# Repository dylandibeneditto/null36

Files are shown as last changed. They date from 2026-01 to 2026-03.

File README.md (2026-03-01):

<picture align="center">
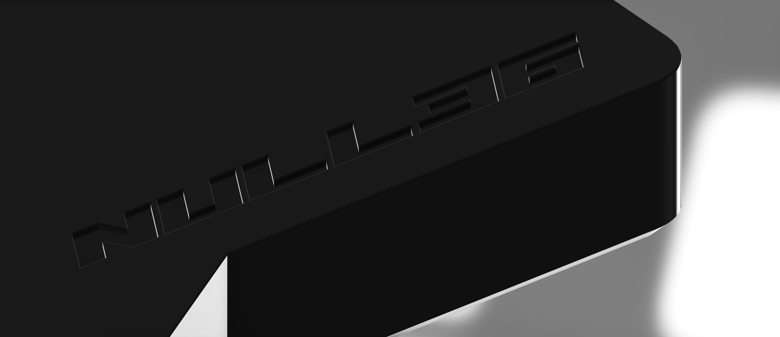
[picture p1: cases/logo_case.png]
null36
    
</picture>

<h1 align="center">null36</h1>

36-Key wireless split ortho column-staggered MX keyboard. Controlled by any Nice!Nano V2 compatible MCU, and support for SSD1306 OLED displays.

# Layout and Keymap

null36 layout

# PCB

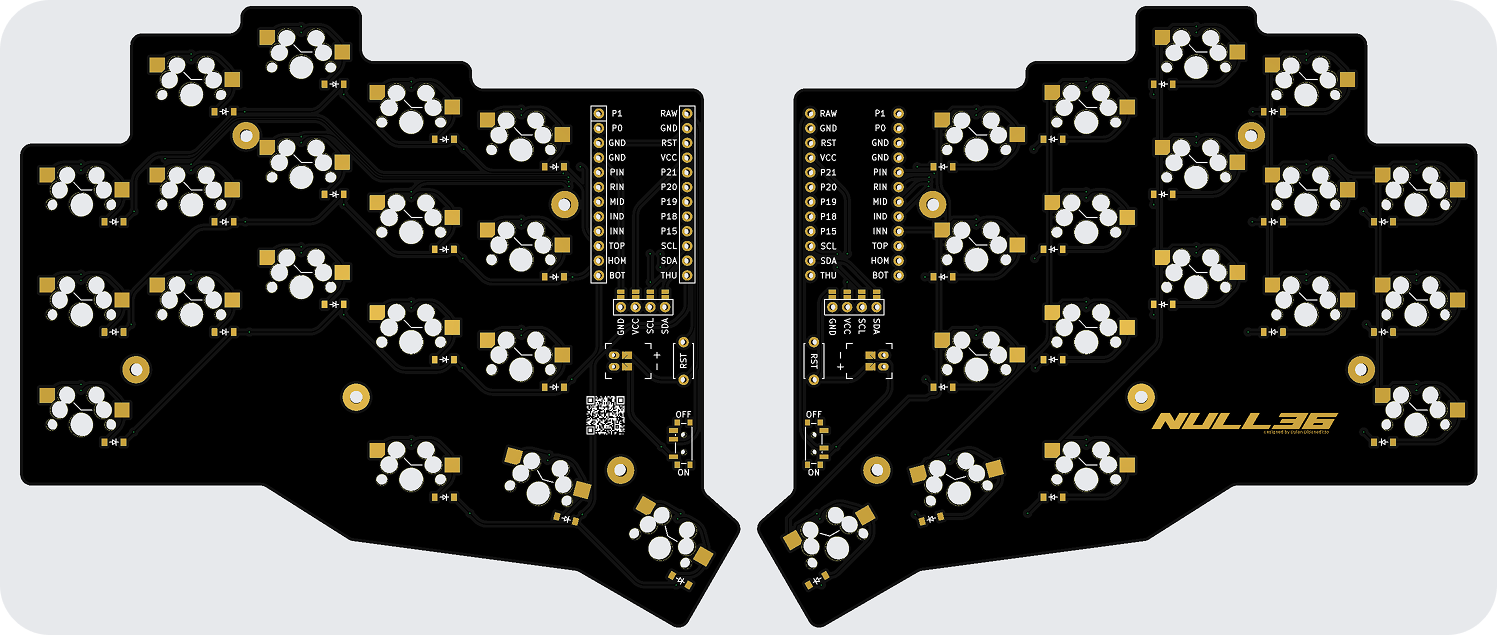
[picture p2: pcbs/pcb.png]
null36 pcb


[/pcbs](./pcbs)
> This PCB is reversible. When assembling, solder together the pads above the OLED display header, the pads next to the battery jack (the jack goes on the underside of the pcb), and diodes can go on either the front or back, as long as they follow the direction of the silkscreen

# Case

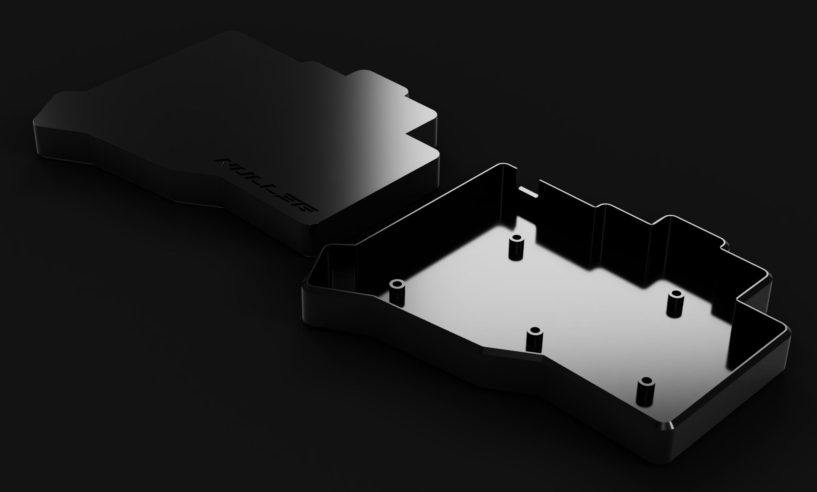
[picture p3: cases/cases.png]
null36 case


[/cases](./cases)

# Photos

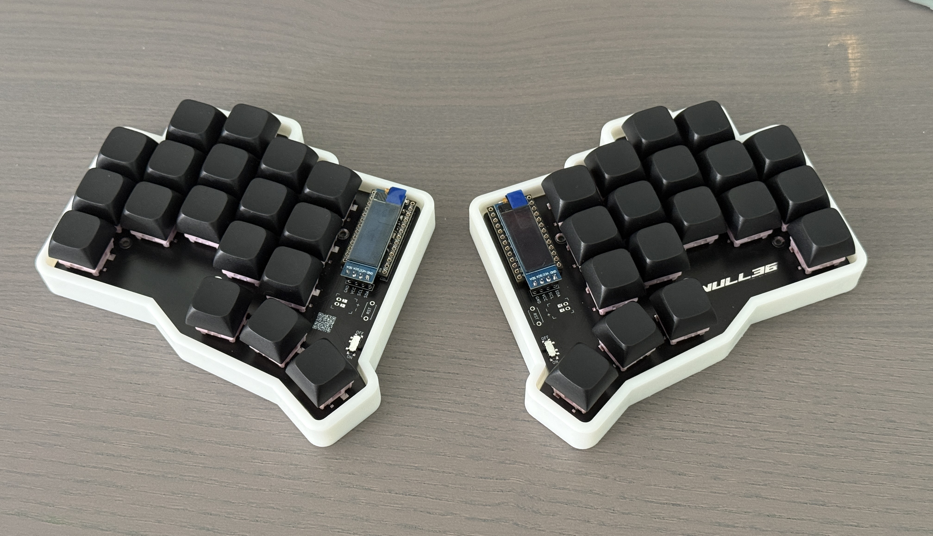
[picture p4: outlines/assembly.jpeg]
Assembly picture


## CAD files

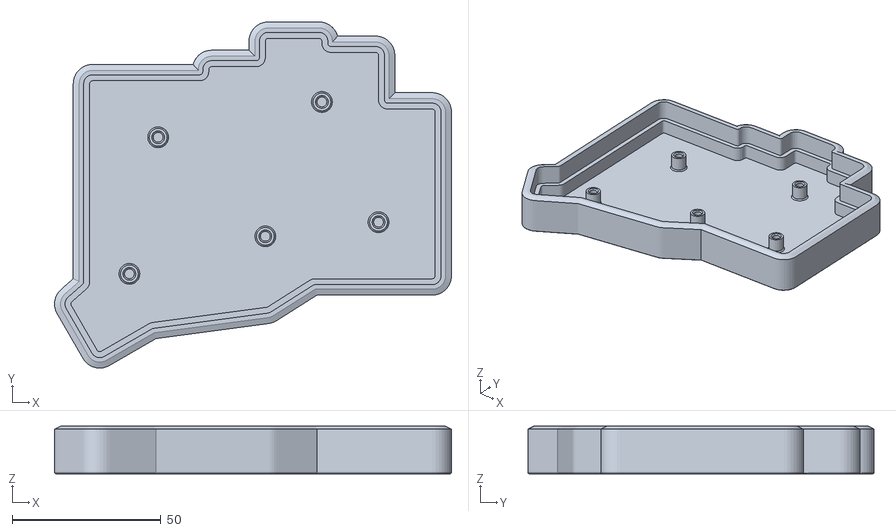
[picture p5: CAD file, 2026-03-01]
cases/right_case.stl
133.3 x 116.2 x 16.0

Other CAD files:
cases/left_case.stl

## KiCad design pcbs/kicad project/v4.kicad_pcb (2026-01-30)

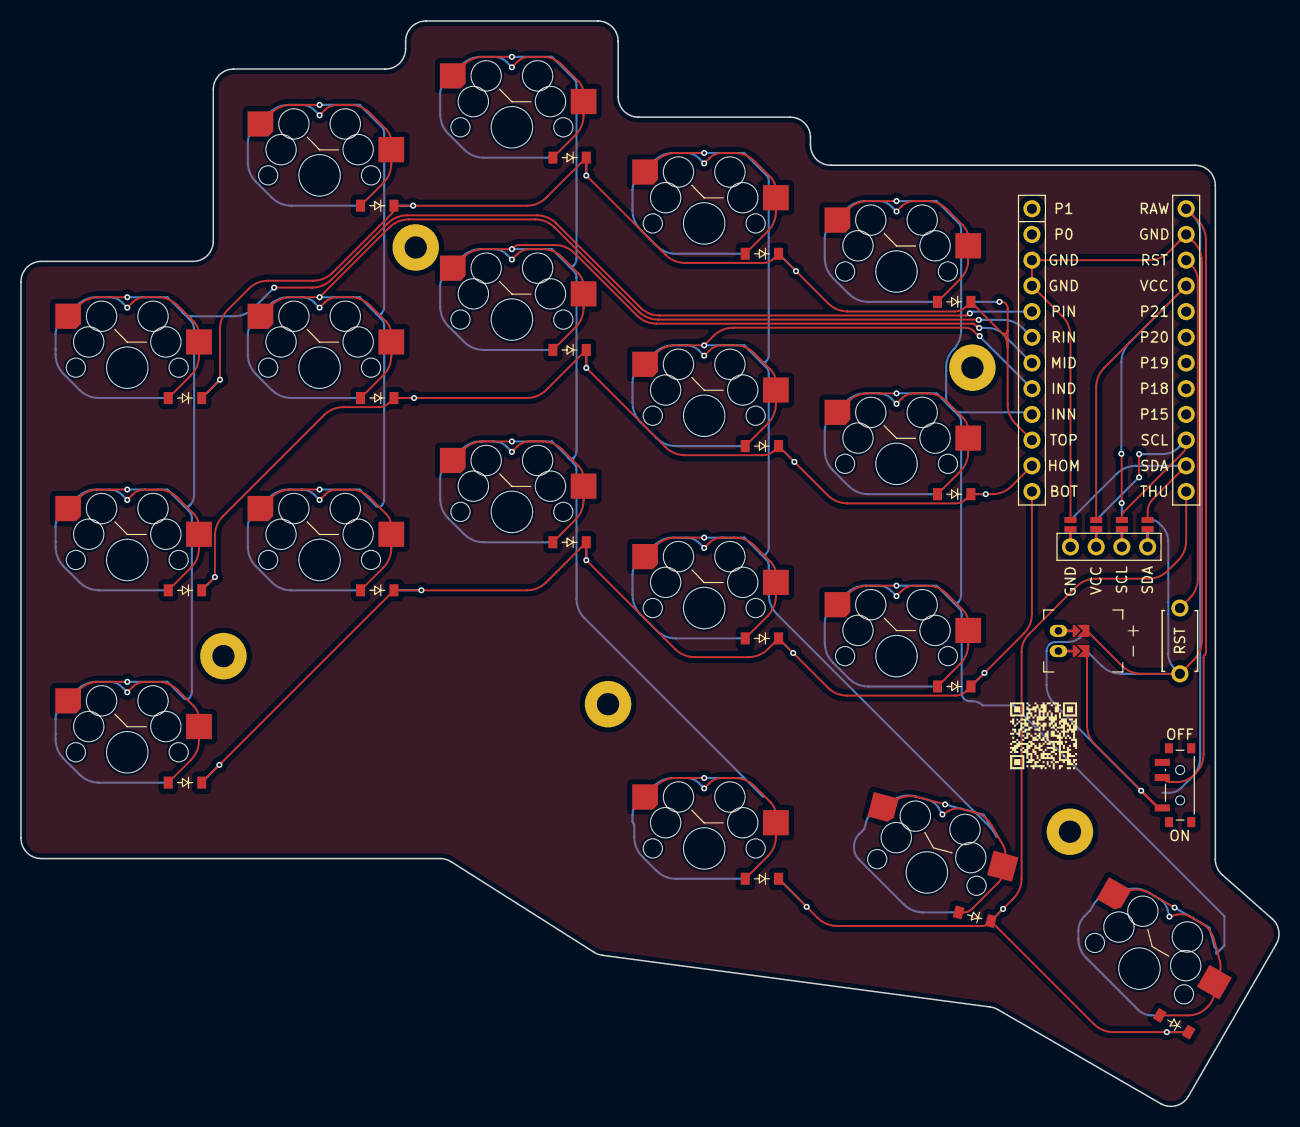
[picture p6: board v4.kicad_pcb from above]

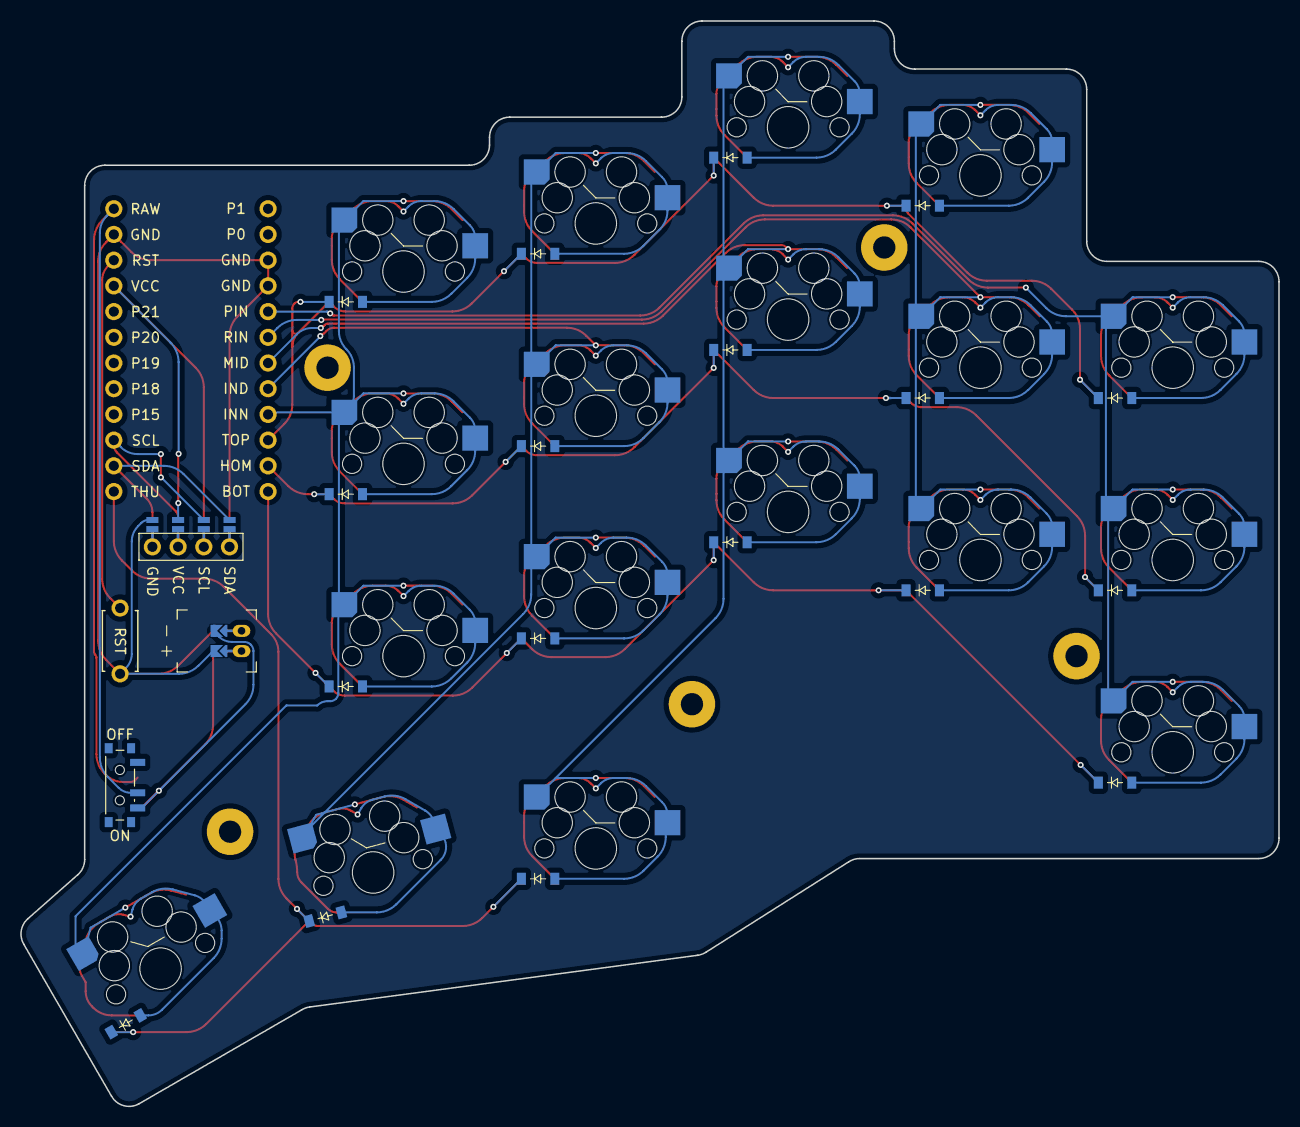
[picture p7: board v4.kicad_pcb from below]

Board: 2 copper layers, 124.3 x 107.2 mm, 46 parts (18 on the bottom side), 40 nets.

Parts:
D1, D2, D3, D4, D5, D6, D7, D8, D9, D10, D11, D12, D13, D14, D15, D16, D17, D18: diode_tht_sod123
DISP1: display_ssd1306
JST1: battery_connector_jst_ph_2
MCU1: mcu_supermini_nrf52840
MH1, MH2, MH3, MH4, MH5: mounting_hole_npth
PWR1: power_switch_smd_side
RST1: reset_switch_tht_top
S1, S2, S3, S4, S5, S6, S7, S8, S9, S10, S11, S12, S13, S14, S15, S16, S17, S18: switch_mx

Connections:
BAT_P: JST1.1, PWR1.1, PWR1.3
BOT: D1.1, D4.1, D7.1, D10.1, D13.1, MCU1.13
DISP1_1: DISP1.1, DISP1.10, DISP1.23
DISP1_2: DISP1.2, DISP1.11, DISP1.22
DISP1_3: DISP1.3, DISP1.12, DISP1.21
DISP1_4: DISP1.4, DISP1.13, DISP1.20
GND: DISP1.14, DISP1.24, JST1.2, MCU1.2, MCU1.21, MCU1.22, RST1.2
HOM: D2.1, D5.1, D8.1, D11.1, D14.1, MCU1.14
IND: MCU1.17, S10.2, S11.2, S12.2, S17.2
IND_BOT: D10.2, S10.1
IND_HOM: D11.2, S11.1
IND_THU: D17.2, S17.1
IND_TOP: D12.2, S12.1
INN: MCU1.16, S13.2, S14.2, S15.2, S18.2
INN_BOT: D13.2, S13.1
INN_HOM: D14.2, S14.1
INN_THU: D18.2, S18.1
INN_TOP: D15.2, S15.1
JST1_1: JST1.11, JST1.21, JST1.31
JST1_2: JST1.12, JST1.22, JST1.32
MID: MCU1.18, S7.2, S8.2, S9.2, S16.2
MID_BOT: D7.2, S7.1
MID_HOM: D8.2, S8.1
MID_THU: D16.2, S16.1
MID_TOP: D9.2, S9.1
PIN: MCU1.20, S1.2, S2.2, S3.2
PIN_BOT: D1.2, S1.1
PIN_HOM: D2.2, S2.1
PIN_TOP: D3.2, S3.1
RAW: MCU1.1, PWR1.2
RIN: MCU1.19, S4.2, S5.2, S6.2
RIN_BOT: D4.2, S4.1
RIN_HOM: D5.2, S5.1
RIN_TOP: D6.2, S6.1
RST: MCU1.3, RST1.1
SCL: DISP1.16, DISP1.26, MCU1.10
SDA: DISP1.17, DISP1.27, MCU1.11
THU: D16.1, D17.1, D18.1, MCU1.12
TOP: D3.1, D6.1, D9.1, D12.1, D15.1, MCU1.15
VCC: DISP1.15, DISP1.25, MCU1.4

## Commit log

2026-01-26 initial pcb design
    [null36.kicad_pcb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]
2026-01-26 v2 of pcb
    [v2.kicad_pcb]
2026-01-26 v3 of pcb
    [v3.kicad_pcb, v3.kicad_sch]
2026-01-26 rearrange directory
    [null36.kicad_pcb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]
2026-01-26 v3 pcb design
    [null36-unrouted.kicad_pcb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]
2026-01-29 v4 pcb design
    [null36-unrouted.kicad_pcb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]
2026-01-30 exporting and start of case
2026-01-30 pcb pictures added
    [v4-B_Cu.gbr, v4-B_Mask.gbr, v4-B_Paste.gbr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]
2026-01-30 case images
2026-01-30 cleanup repo formatting
    [preview.dxf]
2026-03-01 assembly and keymap
    [left_case.stl, right_case.stl]
